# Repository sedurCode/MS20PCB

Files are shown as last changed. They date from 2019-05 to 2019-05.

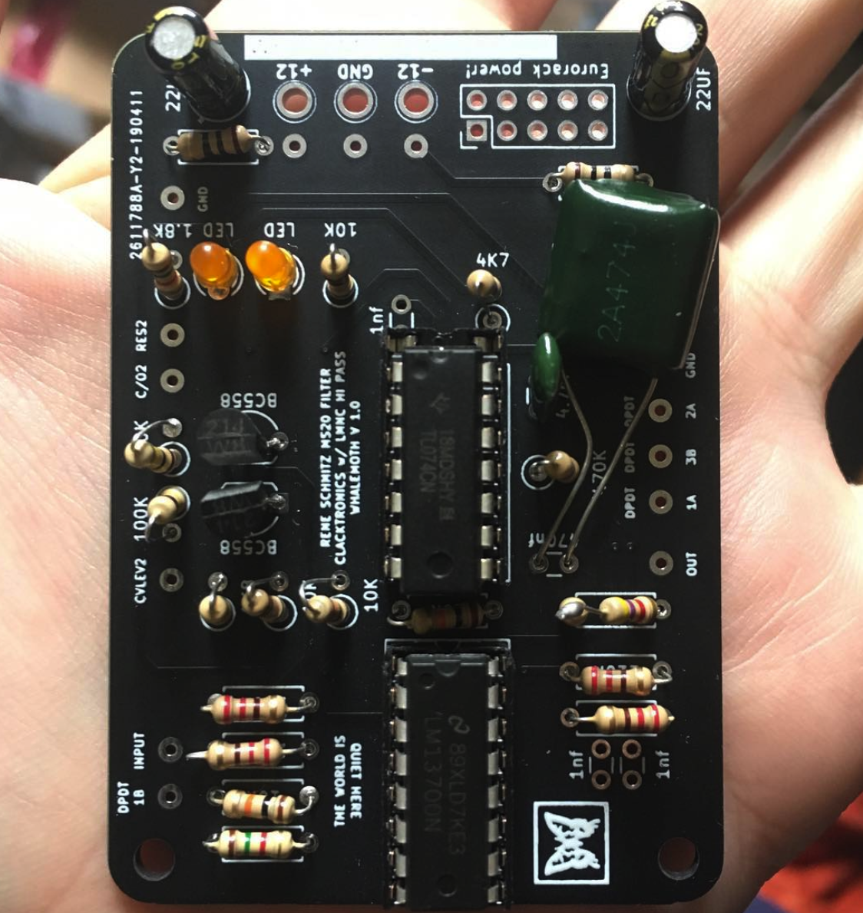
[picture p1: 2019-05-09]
Screenshot 2019-05-09 at 12.46.30.png

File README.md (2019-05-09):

# MS20PCB
These are gerber files &amp; KiCad board file for the LMNC MS20 filter w/ hi pass option

This is based off the Look Mum No Computer version of the Clacktronics version of the Rene Schmitz version of the Korg MS20 filter. 
LMNC laid it out on stripboard and I put it into KiCad cos that's how I do things.
Figured I'd share it for other learners.

NB: This is designed for use with Doepfer Eurorack-style systems. So if you want to built it as a standalone you'll need to bring it 12v+/12v-/Ground and connect accordingly. I reccomend the Frequency Central power bus as a cost effective tool for total beginners. 

Version history:
Currently on V2.0. V1.0 had a broken ground trace from pin 9 of the opamp. Added quality of life changes incl:
-via mounting holes, 
-bigger footprints for larger capacitors,
-clearer DPDT links. 

Not really sure how github works so feel free to reach out! Peace

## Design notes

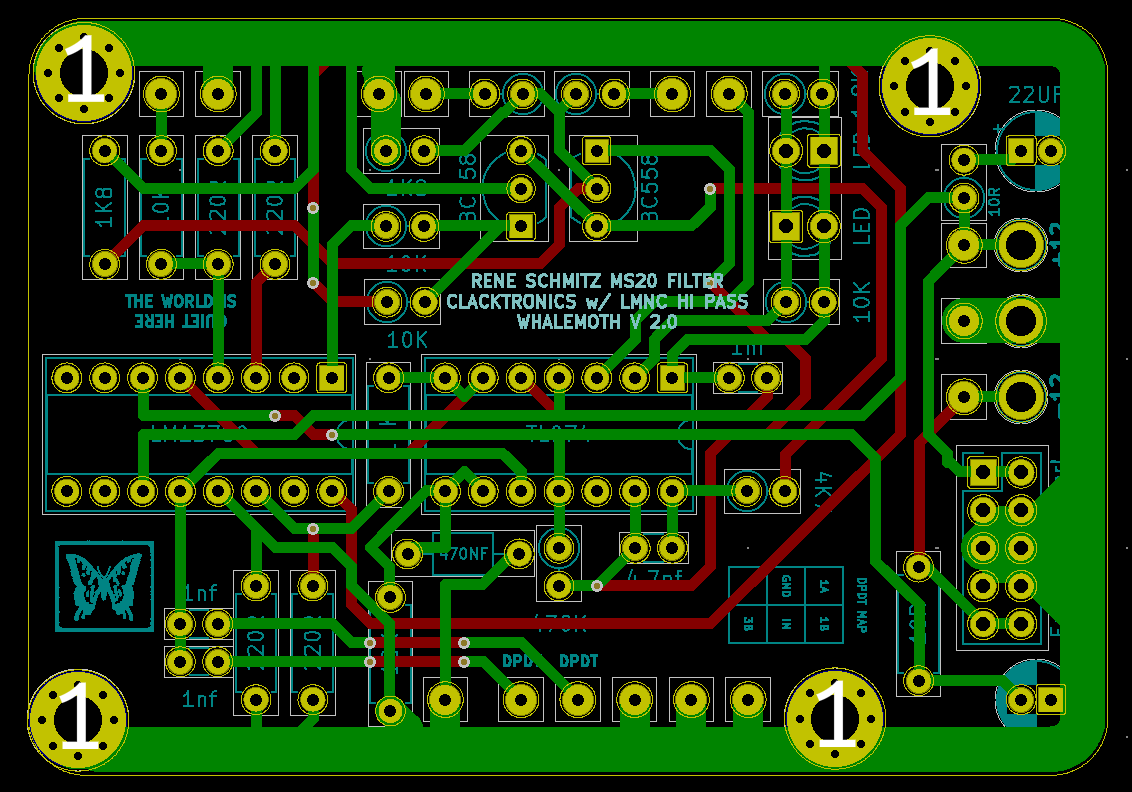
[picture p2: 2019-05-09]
Screenshot 2019-05-09 at 12.43.21.png

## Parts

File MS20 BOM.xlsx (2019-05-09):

Item | Quantity
1K8 | 3
10K | 5
10R | 2
100k | 2
220R | 4
4K7 | 2
470K | 1
22uf Electrolytic | 2
1nf disc | 2
470nf | 1
4.7nf | 1
Eurorack power header? | 1
LED | 2
DPDT | 1
LM13700 | 1
TL074 | 1
14pin DIP socket | 1
16 pin DIP socket | 1
*Can just use 2x 16 pin and cut some pins off
BC558 | 2
100KB potentiometer | 2
5.7KB potentiometer | 1
Jack socket | 3
M3 Standoff pin | 4 ≥ n

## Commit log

2019-04-30 Attached are gerber files and drill files.
    [MS20filter-B_Cu.gbr, MS20filter-B_Mask.gbr, MS20filter-B_Paste.gbr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]
2019-05-09 Delete MS20filter.kicad_pcb
    outdate
    [MS20filter.kicad_pcb]
2019-05-09 Version 2.0!
    This fixes broken ground trace from pin 9 of the opamp. Also includes quality of life changes such as more & bigger mounting holes, bigger traces for large capacitor, and bill of materials. Contains complete Gerber files & kicad board file. Peace!
    [MS20filter-B_Cu.gbr, MS20filter-B_Mask.gbr, MS20filter-B_Paste.gbr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]
2019-05-09 pilot screen using less stringent inclusion criteria
    [MS20filter.sch]
